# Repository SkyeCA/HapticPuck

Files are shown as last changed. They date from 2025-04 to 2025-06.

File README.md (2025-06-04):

# HapticPuck

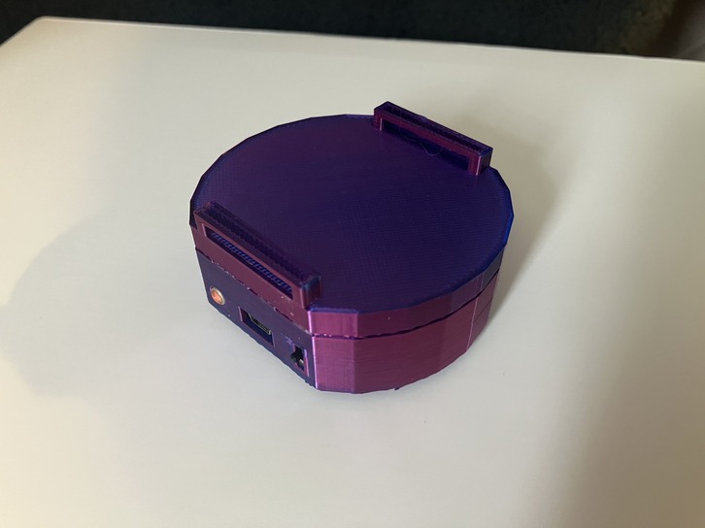
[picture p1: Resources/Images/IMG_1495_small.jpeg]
The first working version of the Puck


This repo contains all the code, models, and other resources needed to create a small, general purpose haptic feedback device.

The primary use case for this project is as a Haptic feedback device for VRChat (and a custom OSC router is included), but if you know how to code, or have basic knowledge of OSC than it could be used for a wide range of applications.

__Warning: This is a work in progress. You should consider this project to be prototype quality currently!__

## Disclaimer

I am just some random hobbyist on the internet who is sharing their personal project. This device has not been formally tested and I am not trained in electronic design/theory.

**Everything in this repo is to be used AT YOUR OWN RISK.**

If you build this device or use any component of this project you agree that I will not be held personally responsible for any harm that comes to you and/or others as a result of it.

## Supported Hardware

- NodeMCU
    - Fully tested and confirmed working, but not used in final design.
- Wemos D1 Mini
    - Fully tested and confirmed working

## Build Requirements

**Parts:**

| Item | Part # | Qty |
|---|---|-----|
| Wemos Mini D1 | (No PN, can be found online) | 1 |
| Switch | 679-2452-ND (Digikey) | 1 |
| Switch | CKN9559-ND (Digikey) | 1 |
| 220uF 25v Capacitor | 1189-4161-ND (Digikey) | 1 |
| Red 3mm LED | 732-5006-ND (Digikey) | 1 |
| JST 2.5mm 2pos Connector | 455-S2B-EH-ND (Digikey) | 1 |
| JST 2.5mm 3pos Connector | 455-S3B-EH-ND (Digikey) | 1 |
| 20K 1/8W Axial Resistor | CF18JT20K0CT-ND (Digikey) | 1 |
| 1K 0.4W Axial Resistor | BC1.00KXCT-ND (Digikey) | 2 |
| 56ohm 0.4W Axial Resistor | 56-MRS16000C5609FCT00CT-ND (Digikey) | 1 |
| 10K | BC10.0KXCT-ND (Digikey) | 2 |
| 18350 Battery Holder | 36-1101-ND (Digikey) | 1 |
| 2N2222 NPN Transistor | 511-2N2222  (Mouser) | 2 |
| 10MM Phone Vibrator | JYC1030 (Digikey) | 2-4 |
| AMS1117 Module |  B0CWGPHK16 (Amazon ASIN) | 1 |
| TP4056 Module |  B07X8XPF74 (Amazon ASIN) | 1 |
| 18350 Rechargeable Li-ion Battery | (No PN, can be found online) | 1 |
| NHD-HP P1 PCB | Can be ordered from a service like OSHPark | 1 |
| Platinum silicone | Kits can be found on Amazon | ? |
-----------------------

**Non-parts:**
- The ability to 3d print.
    - Check out your local library, many have 3d printers these days for use at very low cost!
- The ability and tools to solder.
- Patience

## Repo Layout

### Case/

This folder contains all the 3D models used for the HapticPuck. These were created in SketchUp 2017 and I have provided both .DAE exports of the models and Gcode files for 3d printing.

The Gcode files were generated for my printer, the Elegoo Neptune 3 Pro and I can not guarantee they'll print fine on other 3D printers.

### PCB/

KiCAD schematic and PCB layout files. This is pretty self-explanatory.

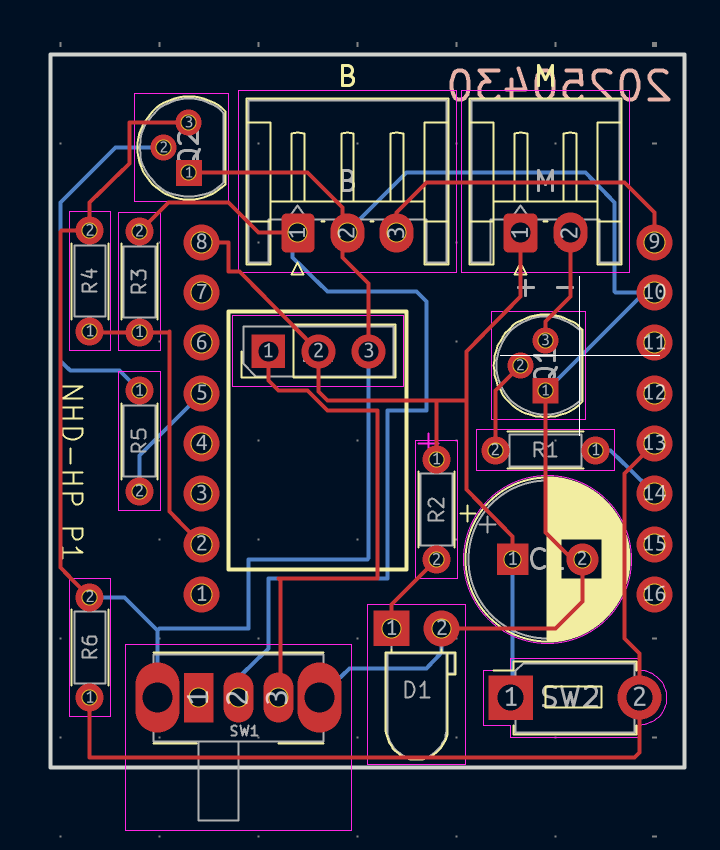
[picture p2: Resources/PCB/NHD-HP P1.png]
First HapticPuck Prototype PCB Layout

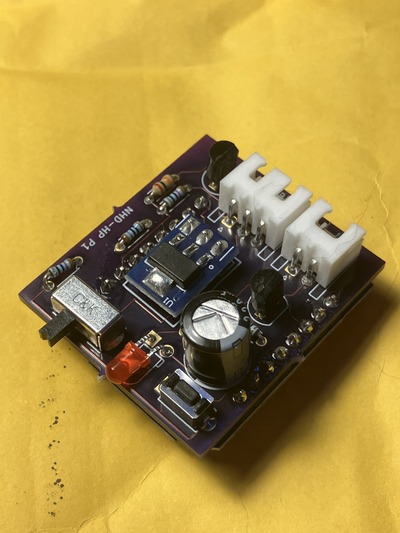
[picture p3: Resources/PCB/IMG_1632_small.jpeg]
First HapticPuck Prototype PCB Assembled


### Firmware/

This folder contains different versions of the firmware for the microcontroller(s) that can run this project.

### NhdRouterServer/

A custom OSC router primarily intended for getting OSC commands from VRChat and forwarding them to the HapticPuck in a format that the firmware can understand.

### Resources/

Random repo specific resources like the image at the top of this readme.

## Images

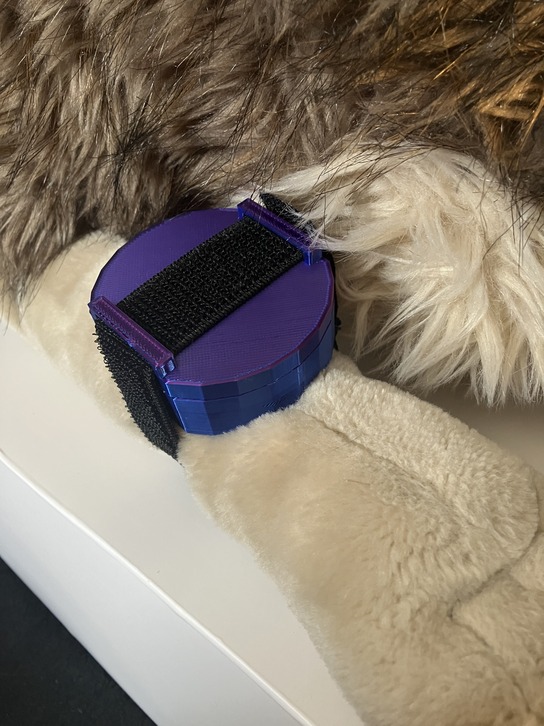
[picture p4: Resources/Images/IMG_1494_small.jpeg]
The puck being worn


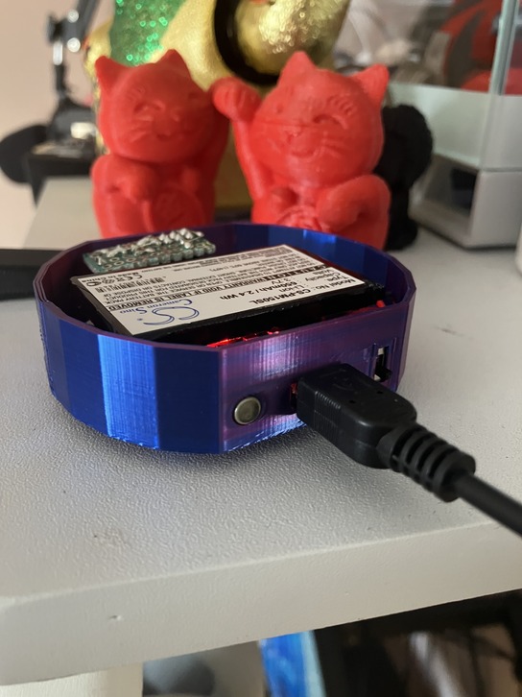
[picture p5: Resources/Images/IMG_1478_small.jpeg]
Internal view of the puck


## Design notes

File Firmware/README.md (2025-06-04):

# Firmware

## HapticPuck_WemosD1Mini_FW

Wemos D1 Mini specific firmware.

### Compatibility

- Physically tested on the NodeMCU 0.9 and Wemos D1 Mini
- Wemos D1 Mini is the target device.

### Naming

<ins>AP Name:</ins> NHD-HapticPuck-[chipId], ex: `nhd-hapticpuck-AA0FD3`

<ins>Hostname:</ins> nhd-hapticpuck-[chipId], ex: `nhd-hapticpuck-AA0FD3`

### Services Provided

- mDNS
    - Advertises itself as `nhd` protocol on TCP port `7593`
- HTTP
    - Listens on port `7593`

### Library Versions

WiFiManager 2.0.17

### Endpoints

All responses are `text/plain` unless otherwise stated.

- / [GET]
    - Returns: 
        - 200:
            - `Ok`
- /battery/percent [GET]
    - Returns: 
        - 200:
            - `87`
- /battery/voltage [GET]
    - Returns: 
        - 200:
            - `3.7`
- /reset [GET]
    - Returns: 
        - 200:
            - `Ok`
    - Notes: Factory Resets Device Immediately
- /vibrate [GET]
    - Params:
        - `val`: `0..20`
    - Returns:
        - 500:
            - When no `val` parameter is provided.
        - 503:
            - Device battery is depleted, device is disabled.
        - 400:
            - When `val` parameter is outside acceptable range.
        - 200:
            - `Ok`
- /version [GET]
    - Returns: 
        - 200:
            - A version string, ex: `0.2`
- /copyright [GET]
    - Returns: 
        - 200:
            - A copyright notice, ex: `(C) 2025 SkyeCA - https://github.com/SkyeCA`
- /cat [GET]
    - Returns: 
        - 200:
            - `Meow (=･ω･=)`
- /id [GET]
    - Returns: 
        - 200:
            - `nhd-hapticpuck-AA0FD3`
- /compatibility [GET]
    - Returns: 
        - 200:
            - `HapticPuck3/nhd`

### Serial Debug Settings

9600/8/N/1

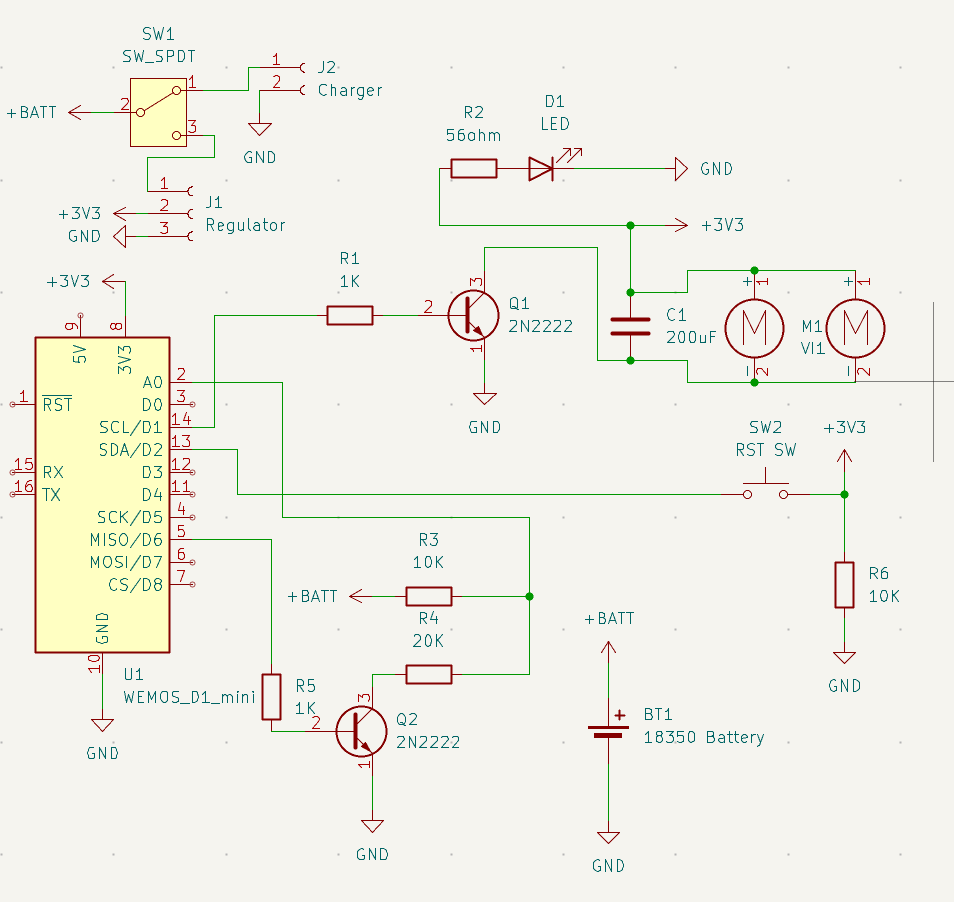
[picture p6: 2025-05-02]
Resources/Diagrams/Schematic Rev1.png

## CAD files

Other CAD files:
Case/V1/Model/Case.skp
Case/V1/Model/Lid.skp
Case/V1/Model/Lid~.skp
Case/V2/Model/Case Mold.skp
Case/V2/Model/CaseAndLidRev2.skp

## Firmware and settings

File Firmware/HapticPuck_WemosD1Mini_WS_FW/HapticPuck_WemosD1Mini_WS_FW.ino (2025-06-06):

#define WEBSERVER_H // Required to prevent collision between WebRequestMethod defined in WifiManager and ESPAsyncWebServer
#define NETWORK_PORT 7593
#define VIBRATOR_PIN D1
#define BATTERY_READ_EN_PIN D6
#define BATTERY_READ_PIN A0
#define RESET_BUTTON_PIN D2
#define VERSION "0.4"
#define MIN_VIBRATE 75
#define STEP_VAL 7.5
// The following numbers account for voltage divider differences! Ex. 410 * 0.0032 = 1.31
// 1.31v would be far too low for a li-ion battery, but the voltage divider difference needs to be added: 1.31 + 1.4 = 2.71
#define BATTERY_DISCHARGE_STEPS 410
#define BATTERY_LOW_STEPS 530
#define BATTERY_CHARGED_STEPS 875
#define VOLTAGE_DIVIDER_DIFF_VOLTS 1.4
#define ADC_STEP_DIVISION_VOLTS 0.0032

#include <WiFiManager.h> // 2.0.17
#include <Arduino.h>
#include <ESP8266WiFi.h>
#include <ESPAsyncTCP.h>
#include <ESPAsyncWebServer.h>
#include <ESP8266mDNS.h>

char deviceId[28];
int batterySteps;
bool lowBattery, depletedBattery = false;
unsigned long lastBatteryCheckMillis;
WiFiManager wifiManager;
AsyncWebServer server(NETWORK_PORT);
AsyncWebSocket ws("/ws");

void ICACHE_RAM_ATTR resetDevice(){
  Serial.println("Factory reset in progress.");
  WiFi.disconnect(true);
  ESP.eraseConfig();
  ESP.restart();
}

void lowBatteryStateHandler(){
  if(!lowBattery && batterySteps <= BATTERY_LOW_STEPS){
    lowBattery = true;
    ws.textAll("BAT_LOW");
    //vibrate motor in a pattern here
  }

  if(!depletedBattery && batterySteps <= BATTERY_DISCHARGE_STEPS){
    depletedBattery = true;
    ws.textAll("BAT_EMPTY");
  }
}

void updateBatteryState(){
  if (millis() - lastBatteryCheckMillis >= 30*1000UL) {
    lastBatteryCheckMillis = millis();  
   
    digitalWrite(BATTERY_READ_EN_PIN, HIGH);
    delay(200);
    batterySteps = analogRead(BATTERY_READ_PIN);
    digitalWrite(BATTERY_READ_EN_PIN, LOW);

    Serial.print("New battery level: ");
    Serial.println(batterySteps);

    lowBatteryStateHandler();
  }
}

float calculateBatteryVoltage(){
  return (ADC_STEP_DIVISION_VOLTS * batterySteps) + VOLTAGE_DIVIDER_DIFF_VOLTS;
}

float calculateBatteryPercent(){
  return ((batterySteps-BATTERY_DISCHARGE_STEPS) * 100) / (BATTERY_CHARGED_STEPS - BATTERY_DISCHARGE_STEPS);
}

void handleVibrate() {
  Serial.println("Vibrate Handler Invoked");

  if(depletedBattery){
    Serial.println("Low battery, vibrate disabled.");
    ws.textAll("BAT_LOW_DISABLED");
    return;
  }

  //if(!server->hasArg("val")){
  //  Serial.println("No val provided.");
  //  ws.textAll("No Vibrate Val Provided. [0..20]");
  //  return;
  //}

  //int vibrateValue = server->arg("val").toInt();
  int vibrateValue = 0;

  if(vibrateValue < 0 || vibrateValue > 20){
    Serial.println("Invalid val range");
    ws.textAll("Only range 0..20 is valid");
    return;
  } else if(vibrateValue == 0){
    Serial.println("Turned off");
    analogWrite(VIBRATOR_PIN, 0);
    ws.textAll("Ok");
    return;
  }

  Serial.println("Set vibration level.");
  analogWrite(VIBRATOR_PIN, MIN_VIBRATE + (vibrateValue * STEP_VAL));
  ws.textAll("Ok");
  return;
}

void handleBatteryPercent() {
  Serial.println("Battery Percent Handler Invoked");
  ws.textAll(String(calculateBatteryPercent()));
}

void handleBatteryVoltage() {
  Serial.println("Battery Voltage Handler Invoked");
  ws.textAll(String(calculateBatteryVoltage()));
}

void handleReset() {
  Serial.println("Reset Handler Invoked");
  ws.textAll("Ok");
  resetDevice();
}

void handleVersion() {
  Serial.println("Version Handler Invoked");
  ws.textAll(VERSION);
}

void handleCopyright() {
  Serial.println("Copyright Handler Invoked");
  ws.textAll("(C) 2025 SkyeCA - https://github.com/SkyeCA");
}

void handleCat() {
  Serial.println("Cat Handler Invoked");
  ws.textAll("Meow (=･ω･=)");
}

void handleDeviceId() {
  Serial.println("Device ID Handler Invoked");
  ws.textAll(deviceId);
}

void handleCompatibility() {
  Serial.println("Handle Compatibility Invoked");
  ws.textAll("HapticPuck3/nhdws");
}

void handleWebSocketMessage(void *arg, uint8_t *data, size_t len) {
  AwsFrameInfo *info = (AwsFrameInfo*)arg;
  if (info->final && info->index == 0 && info->len == len && info->opcode == WS_TEXT) {
    data[len] = 0;
    String message = (char*)data;
    // Check if the message is "getReadings"
    if (strcmp((char*)data, "BAT_PCT") == 0) {
      handleBatteryPercent();
    }
  }
}

void onEvent(AsyncWebSocket *server, AsyncWebSocketClient *client, AwsEventType type, void *arg, uint8_t *data, size_t len) {
  switch (type) {
    case WS_EVT_CONNECT:
      Serial.printf("WebSocket client #%u connected from %s\n", client->id(), client->remoteIP().toString().c_str());
      break;
    case WS_EVT_DISCONNECT:
      Serial.printf("WebSocket client #%u disconnected\n", client->id());
      break;
    case WS_EVT_DATA:
      handleWebSocketMessage(arg, data, len);
      break;
    case WS_EVT_PONG:
    case WS_EVT_ERROR:
      break;
  }
}

void setup() {
  Serial.begin(9600);
  Serial.println("Init...");

  // Set device name
  snprintf(deviceId,28, "nhd-hapticpuck-%04X%08X", (uint32_t) ESP.getChipId());
  Serial.print("Device ID is: ");
  Serial.println(deviceId);

  // Setup Pins
  attachInterrupt(RESET_BUTTON_PIN, resetDevice, RISING);

  // Configure Wifi to work with Bell GigaHub
  WiFi.persistent(false);
  WiFi.setPhyMode(WIFI_PHY_MODE_11G);
  WiFi.hostname(deviceId);
  //WiFi.mode(WIFI_STA); 

  // Start WifiManager AP
  Serial.println("WM Start");
  //wifiManager.setDebugOutput(false);
  wifiManager.autoConnect(deviceId);

  // Start mdns
  Serial.println("mDNS Start");
  if (!MDNS.begin(deviceId)) {
    Serial.println("Error setting up MDNS responder!");
    while (1) { delay(1000); }
  }

  // Setup Websocket
  ws.onEvent(onEvent);
  server.addHandler(&ws);
  server.begin();

  // Add mDNS Service
  Serial.println("Add mDNS Service");
  MDNS.addService("nhd", "ws", NETWORK_PORT);

  Serial.println("Ready!");
}

void loop() {
  ws.cleanupClients();
  MDNS.update();
  updateBatteryState();
}

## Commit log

2025-04-24 clean up
    [Lid~.skp]
2025-04-25 Update Lid model strap holders to fit stock quest head strap
    [Lid.skp]
2025-04-25 Control circuit, readme
2025-04-25 Update lid
    [Lid.skp, Lid~.skp]
2025-04-28 Working MDNS based device finder
2025-04-28 KiCad schematic
    [Mini D1 Puck.kicad_pcb, Mini D1 Puck.kicad_sch]
2025-04-28 Add voltage divider to schematic to measure battery level
    [Mini D1 Puck.kicad_sch]
2025-04-28 Ui WORK
    [Mini D1 Puck.kicad_sch]
2025-04-30 NHD Router App State/refactor, HP schematic rework
    [Mini D1 Puck.kicad_pcb, Mini D1 Puck.kicad_sch]
2025-04-30 Kicad PCB
    [Mini D1 Puck-B_Cu.gbr, Mini D1 Puck-B_Mask.gbr, Mini D1 Puck-B_Silkscreen.gbr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]
2025-04-30 remove gerber files
    [Mini D1 Puck-B_Cu.gbr, Mini D1 Puck-B_Mask.gbr, Mini D1 Puck-Edge_Cuts.gbr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]
2025-05-01 PCB fixes/reset button
    [Mini D1 Puck-B_Cu.gbr, Mini D1 Puck-B_Mask.gbr, Mini D1 Puck-B_Silkscreen.gbr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]
2025-05-01 PCB Update. These gerber files were ordered May 1 2025
    [Mini D1 Puck-B_Cu.gbr, Mini D1 Puck-B_Mask.gbr, Mini D1 Puck-B_Silkscreen.gbr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]
2025-05-02 repo cleanup, readme bom
    [Mini D1 Puck.kicad_sch]
2025-05-30 Update firmware, start modeling new case
    [Case.skp, Case~.skp, Lid.skp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]
2025-05-30 New, worse case
    [Case Base.skp, Case Base~.skp]
2025-05-31 Adjust case tollerences
    [Case Base.skp, Case Base~.skp]
2025-06-01 Case issues, silicone mold attempt, fix PCB reset button wiring
    [Mini D1 Puck.kicad_pcb, Silicone Mold.skp, Silicone Mold~.skp]
2025-06-02 model fixes
    [Case Base.skp, Case Base~.skp, Case Mold.skp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]
2025-06-02 Fix battery monitor circuit, voltage divider not properly grounded
    [Mini D1 Puck.kicad_pcb, Mini D1 Puck.kicad_sch]
2025-06-03 firmware battery functions
2025-06-04 Check for low battery conditions and disable device if battery is depleated.
2025-06-04 Firmware wording fix, firmware doc update
    [HapticPuck_WemosD1Mini_FW.ino]
2025-06-06 Work on new schematic, up minimum voltage in firmware
    [Mini D1 Puck.kicad_pcb, Mini D1 Puck.kicad_sch]
